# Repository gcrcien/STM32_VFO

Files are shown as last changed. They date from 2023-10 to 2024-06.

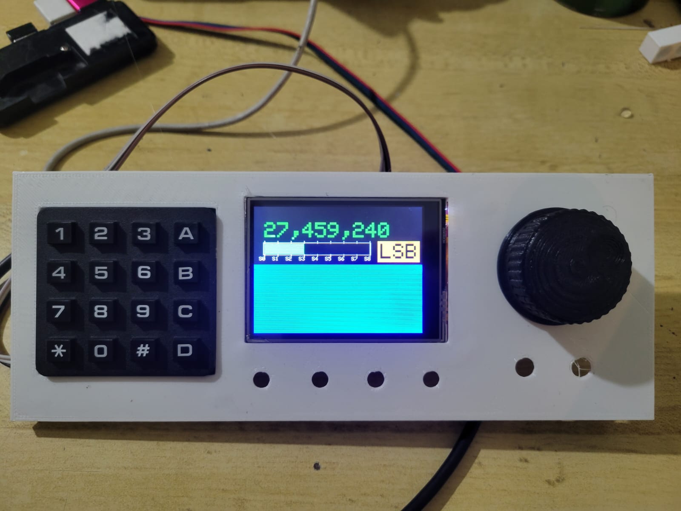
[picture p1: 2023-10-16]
WhatsApp Image 2023-10-15 at 18.07.27.jpeg

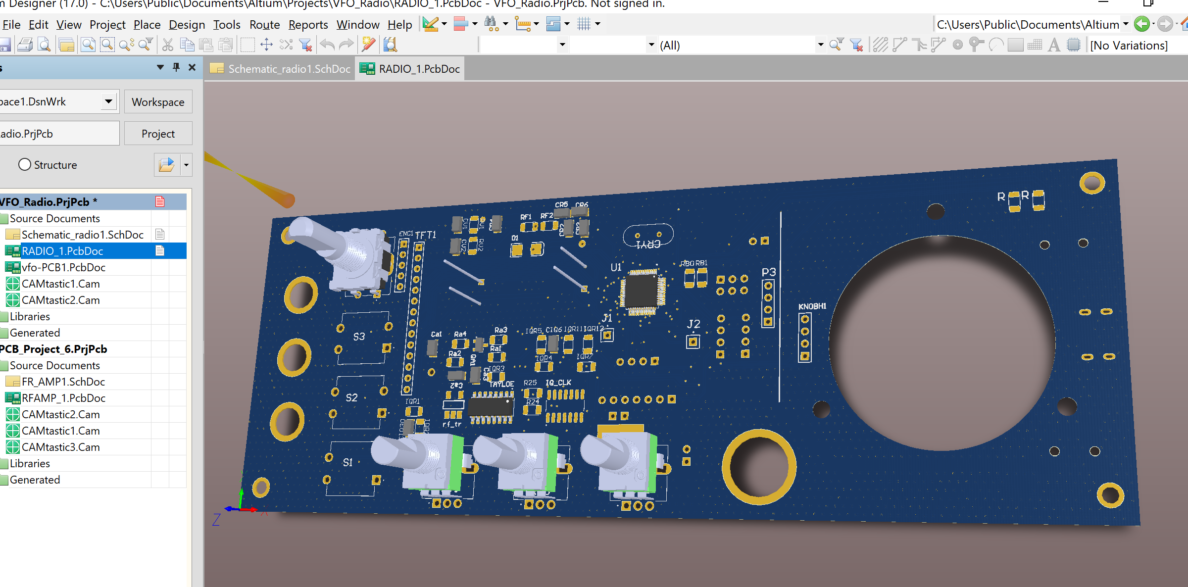
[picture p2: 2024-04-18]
image.png

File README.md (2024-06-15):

# STM32_VFO
VFO for si5351, stm32 and ili9341 2.8" spi tft 

This is the start of a easy to make VFO to use with existing radios or even make your own,
the system interfaces an optical encoder on pins B12 and B13, a big SPI display a clasic tft 2.8 ILI9341,
a matrix 4x4 Keypad using I2C interface with PCF8574, i know the screen has touch inputs
however i like to have a tactile input and the keypad just feels better.

Te MCU is constantly monitoring a few things, for example the audio level on receive.
Some radios use the same meter for audio receive and modulation measurement which this radio would be suited for.

WhatsApp Image 2023-10-15 at 18 07 27 (1)

The system is currently coded with spanish languaje but this would be a simple task to translate.
they Keypad input is activated with the "A" key, asks for a frequency in Hz, when this key is pressed again, and if the frequency is 
whithin acceptable range, the value is passed to the VFO and is desplayed.

WhatsApp Image 2023-11-06 at 07 51 49

Recently i was able to include a simple spectrum view, its just a FFT of the input of my radio, this needs to be downconverted to place the center frequency
of the FFT in the 40khz region, the system shows a 80khz wide view around your frequency of interest, in my case i just tapped my receiver before the IF filter,
this is because the filter is too narrow for more than the desired 2500hz wide area of interest for audio listening.
Its not ideal, the signal is kept into acceptable levels cause i connected the downconverter after the variable gain amp which is controlled by the agc, 
so the signals of interest basically disapear out of the fft view if they are a bit high. Need to fix this, a posible way to do it is basically make a 
mini receiver, so a receiver within a receiver.

Lattest update i have been working on a PCB for the whole project, it handles most fo the VFO part of the system and also includes a Tayloe detector for a realtime sprectrum graph, still needs to be tested, uploaded the Gerber files, PDF and a sch from altium, it also has an IQ output via the 3.5mm jack to connect to sdr++ and act as a SDR via the sound card.


Latest version includes a small waterfall display of the sampled audio 

Watch the video (https://youtu.be/gbz6IhAs6Uw)

More work ahead

18d13fbe-9281-404b-9812-ee0a2d2707f5

This is a work in progress feel free to give me any advice and/or ask any questions

Gustavo :D

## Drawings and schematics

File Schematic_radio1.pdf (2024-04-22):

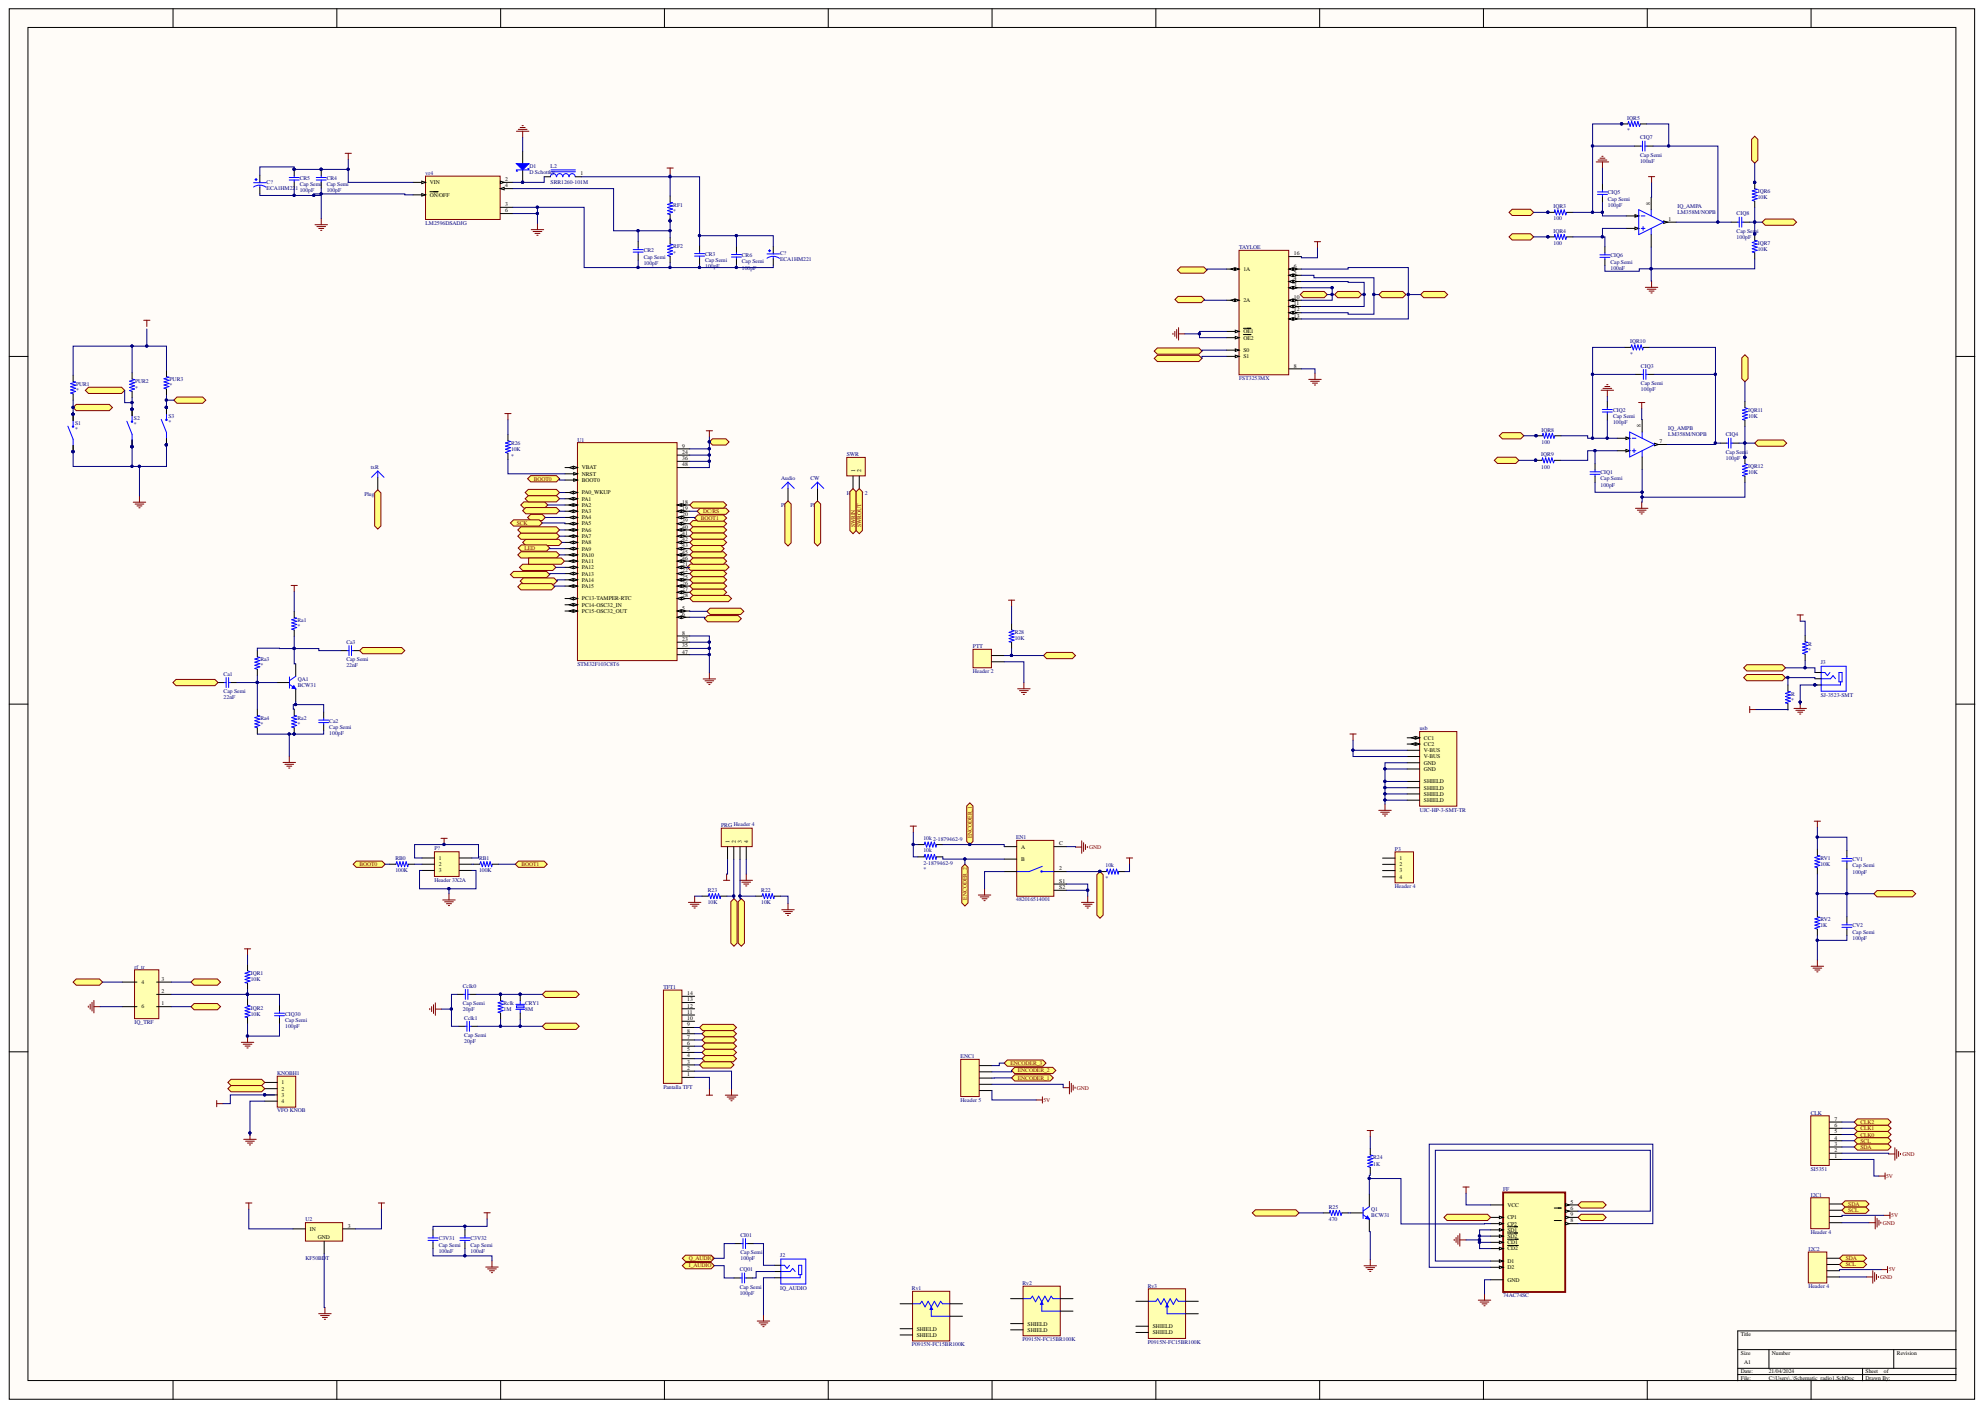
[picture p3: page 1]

UJC-HP-3-SMT-TR

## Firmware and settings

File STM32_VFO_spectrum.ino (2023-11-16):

#include "SPI.h"
#include "Adafruit_ILI9341.h"
#include <Wire.h>
#include <si5351.h>
#include "I2CKeyPad.h"

// Definición de pines para el TFT
#define TFT_CS    PA4
#define TFT_CLK   PA5
#define TFT_MISO  PA6
#define TFT_MOSI  PA7
#define TFT_RST   PB0
#define TFT_DC    PB1
#define AUDIO_IN  PA0

// Constantes para la barra de audio
#define SCALE_X_OFFSET 20
#define AUDIO_BAR_Y_OFFSET 70
#define SCALE_WIDTH 200
#define SCALE_HEIGHT 20
#define NUM_SEGMENTS 9

//Definiciones de la FFT
#define TFT_WIDTH 500
#define TFT_HEIGHT 80
#define GRAPH_TOP_MARGIN 4
#define GRAPH_BOTTOM_MARGIN 4
unsigned int sampling_period_us;
#include "arduinoFFT.h"

arduinoFFT FFT;

#define CHANNEL PA3
const uint16_t samples = 256;
const double samplingFrequency = 100000;
unsigned long microseconds;
int micro1;
unsigned int micro2;
int FFToffset = 29000;
double vReal[samples];
double vImag[samples];

#define SCL_INDEX 0x00
#define SCL_TIME 0x01
#define SCL_FREQUENCY 0x02
#define SCL_PLOT 0x03



// Frecuencia actual
unsigned long currentFrequency = 27185000;

// Inicialización del objeto TFT
Adafruit_ILI9341 tft = Adafruit_ILI9341(TFT_CS, TFT_DC, TFT_RST);

// Dirección del teclado I2C
const uint8_t KEYPAD_ADDRESS = 0x20;
I2CKeyPad keyPad(KEYPAD_ADDRESS);

// Inicialización del Si5351
Si5351 si5351;

// Rangos de frecuencia
unsigned long minFrequency = 26000000;     // Frecuencia mínima de 26 MHz
unsigned long maxFrequency = 28500000;     // Frecuencia máxima de 28.5 MHz
unsigned long frequencyStep = 1000;

// Mapeo de teclas del teclado
char keymap[19] = "D#0*C987B654A321NF";

// Variables para la entrada de frecuencia desde el teclado
String inputNumber = "";
bool inputMode = false;

// Bandera para cambios de frecuencia
bool change = false;

// Offset de frecuencia para mi radio/mezclador
long int IFoffset = 10694700;
int ssbofset = 2500;
int comp = 100;

// Segmento actual en la barra de audio
int segment = 0;

// Cadena de la frecuencia anterior
String oldFrequency_string;

// Intervalo de actualización de audio
unsigned long lastAudioUpdate = 0;
unsigned long audioUpdateInterval = 1;

// Variables para construir la cadena de frecuencia
String shz;
String skhz;
String smhz;
String frequency_string;
//tx state value
bool txState;

// Modo de operación (LSB, AM, USB)
String mode = "LSB";
bool sideband;
bool previousSide;

// Segmento actual en el espectro
int newSegment;

// Valor de entrada de audio
int audioValue;

//PTT
bool ptt = 0;

// Bandera para la exploración de frecuencias
bool scan = false;

void setup() {
  // Inicialización del TFT
  tft.begin();
  tft.setRotation(1);
  tft.fillScreen(ILI9341_BLACK);
  tft.setTextColor(ILI9341_WHITE);
  tft.setTextSize(1);

  //definicion de la frecuencia de muestreo para la fft
  sampling_period_us = round(1000000 * (1.0 / samplingFrequency));


  // Configuración de pines y habilitación de interrupciones para el control de frecuencia
  pinMode(PB12, INPUT_PULLUP);
  pinMode(PB13, INPUT_PULLUP);
  pinMode(PA10, INPUT);
  pinMode(PA9, INPUT);
  attachInterrupt(digitalPinToInterrupt(PB12), clock1_ISR, FALLING);
  attachInterrupt(digitalPinToInterrupt(PB13), clock1_ISR2, FALLING);

  // Inicialización de SPI
  SPI.beginTransaction(SPISettings(20000000, MSBFIRST, SPI_MODE0));

  // Dibujo de la escala en el TFT
  tft.fillRect(0, 110, 320, 240, ILI9341_BLUE);
  drawScale();

  // Actualización del reloj y el modo
  clock_update();
  get_mode();

  // Inicialización de la comunicación I2C y carga del mapeo del teclado
  Wire.begin();
  Wire.setClock(400000);
  keyPad.loadKeyMap(keymap);

  //FFT y sus marcos
  tft.fillRect(1, 151, 250, 76, ILI9341_BLACK);
  tft.drawRect(0, 150, 252, 77, ILI9341_WHITE);
  for (int x = 25; x <= 252; x += 25) {
    tft.drawFastVLine(x, 225, 8, ILI9341_WHITE);
  }

  // Agregar los números desde -25 kHz hasta +25 kHz
  for (int i = 0; i <= 50; i += 5) {
    int i2;
    tft.setTextColor(ILI9341_WHITE);
    tft.setTextSize(0);
    tft.setCursor(2 + (i ) * 5, 230); // Ajusta las coordenadas según tus necesidades
    if (i < 25) {
      i2 = (( i - 25) *  - 1);
    }
    else {
      i2 = i - 25;
    }
    tft.print(i2);
  }



  // Inicialización del Si5351
  si5351.init(SI5351_CRYSTAL_LOAD_8PF, 0, 0);
  si5351.drive_strength(SI5351_CLK0, SI5351_DRIVE_8MA);
  si5351.output_enable(SI5351_CLK0, 1);
  si5351.drive_strength(SI5351_CLK2, SI5351_DRIVE_2MA);
  si5351.output_enable(SI5351_CLK2, 1);
  si5351.set_freq((27175000) * SI5351_FREQ_MULT, SI5351_CLK2);

  //BORRAR DESPUES
  ptt = digitalRead(PA10);
  tft.fillRoundRect(235, 110, 80, 40, 2, ILI9341_GREEN);
  tft.setCursor(250, 115);
  tft.setTextSize(4);
  tft.setTextColor(ILI9341_BLACK);
  tft.print("RX");
  ptt = digitalRead(PA10);
  sideband = digitalRead(PA9);
  if (!sideband) {
    mode = "USB";
    IFoffset = 10697200 - ssbofset;  // Procesamiento del teclado
  }

  if (sideband) {
    mode = "LSB";
    IFoffset = 10697200 + ssbofset;       // Procesamiento del teclado
  }
  get_mode();
  if (ptt) {
    tft.setCursor(250, 115);
    tft.setTextSize(4);
    tft.setTextColor(ILI9341_BLACK);
    tft.print("TX");
  }

}

// Manejador de interrupción para el control de frecuencia (giro de perilla)
void clock1_ISR() {
  bool dir = digitalRead(PB13);
  if (dir == true) {
    currentFrequency += 10;
  }
  if (dir == false) {
    currentFrequency -= 10;
  }
  change = true;
}

// Manejador de interrupción para el control de frecuencia (giro de perilla)
void clock1_ISR2() {
  bool dir = digitalRead(PB12);
  if (dir == true) {
    currentFrequency -= 10;
  }
  if (dir == false) {
    currentFrequency += 10;
  }
  change = true;
}

// Dibuja la escala en el TFT
void drawScale() {
  tft.drawRect(SCALE_X_OFFSET - 2, AUDIO_BAR_Y_OFFSET - 2, SCALE_WIDTH + 4, SCALE_HEIGHT + 4, ILI9341_WHITE);
  int segmentWidth = SCALE_WIDTH / NUM_SEGMENTS;
  int scaleValue = 0;
  tft.drawRect(SCALE_X_OFFSET, AUDIO_BAR_Y_OFFSET, SCALE_WIDTH, SCALE_HEIGHT, ILI9341_WHITE);
  for (int i = 0; i <= NUM_SEGMENTS; i++) {
    int x = SCALE_X_OFFSET + i * segmentWidth;
    tft.drawFastVLine(x, AUDIO_BAR_Y_OFFSET - 5, SCALE_HEIGHT + 10, ILI9341_WHITE);
    tft.setCursor(x - 10, AUDIO_BAR_Y_OFFSET + SCALE_HEIGHT + 5);
    tft.setTextSize(1);
    tft.setTextColor(ILI9341_WHITE);
    tft.print("S" + String(scaleValue));
    scaleValue += 9 / NUM_SEGMENTS;
  }
}

// Actualiza la visualización del número de entrada en el TFT
void updateInputNumberDisplay() {
  tft.setCursor(30, 10);
  tft.setTextSize(2);
  tft.setTextColor(ILI9341_GREEN);
  tft.print(inputNumber);
}

// Actualiza la información de frecuencia en el TFT
void clock_update() {
  f_string();
  tft.setCursor(20, 30);
  tft.setTextSize(4);
  tft.setTextColor(ILI9341_BLACK);
  tft.print(oldFrequency_string);
  tft.setCursor(20, 30);
  tft.setTextSize(4);
  tft.setTextColor(ILI9341_GREEN);
  tft.print(frequency_string);
  oldFrequency_string = frequency_string;
  change = false;
}

// Lee el valor de entrada de audio
void audio_peek() {
  audioValue = analogRead(AUDIO_IN);

  // Calcula el nuevo segmento
  newSegment = audioValue / (600 / NUM_SEGMENTS);

  // Limita el nuevo segmento para que no sea mayor que NUM_SEGMENTS - 1
  if (newSegment >= NUM_SEGMENTS) {
    newSegment = NUM_SEGMENTS - 1;
  }

  if (newSegment != segment) {
    tft.fillRoundRect(SCALE_X_OFFSET, AUDIO_BAR_Y_OFFSET, SCALE_WIDTH, SCALE_HEIGHT, 2, ILI9341_BLACK);

    int segmentWidth = SCALE_WIDTH / NUM_SEGMENTS;
    segment = newSegment;

    for (int i = 0; i <= segment; i++) {
      int x = SCALE_X_OFFSET + i * segmentWidth;
      if (i >= NUM_SEGMENTS - 1) {
        tft.fillRoundRect(x, AUDIO_BAR_Y_OFFSET, segmentWidth, SCALE_HEIGHT, 2, ILI9341_RED);
      } else if (i == 6 || i == 7) {
        tft.fillRoundRect(x, AUDIO_BAR_Y_OFFSET, segmentWidth, SCALE_HEIGHT, 2, ILI9341_YELLOW);
      } else {
        tft.fillRoundRect(x, AUDIO_BAR_Y_OFFSET, segmentWidth, SCALE_HEIGHT, 2, ILI9341_GREEN);
      }
    }
  }
}

// Construye la cadena de frecuencia en formato MHz, kHz y Hz
void f_string() {
  int mhz = currentFrequency / 1000000;
  int khz = (currentFrequency % 1000000) / 1000;
  int hz = currentFrequency - ((mhz * 1000000) + (khz * 1000));

  smhz = String(mhz);
  if (mhz < 10 && mhz >= 1) {
    smhz = " " + String(mhz);
  }

  if (hz >= 100) {
    shz = "," + String(hz);
  }
  if (hz < 100 && hz > 10) {
    shz = ",0" + String(hz);
  }
  if (hz < 10 && hz >= 1) {
    shz = ",00" + String(hz);
  }
  if (hz == 0) {
    shz = ",000";
  }

  if (khz >= 100) {
    skhz = "," + String(khz);
  }
  if (khz < 100 && khz > 10) {
    skhz = ",0" + String(khz);
  }
  if (khz < 10 and khz >= 1) {
    skhz = ",00" + String(khz);
  }
  if (khz == 0) {
    skhz = ",000";
  }

  frequency_string = smhz + skhz + shz;
}

// Procesa la entrada del teclado
void keypadInput() {
  int oldClock = currentFrequency;
  char ch = keyPad.getChar();
  int key = keyPad.getLastKey();
  if (ch == '*') {
    scan = !scan;
  }

  if (ch == 'A') {
    if (!inputMode) {
      inputMode = true;
      inputNumber = "";
    } else {
      int number = inputNumber.toInt();
      inputMode = false;

      change = true;
      if (number > 21000 && number < 50000) {
        currentFrequency = (number * 1000);
      }
      else if (number < 21000 || number > 50000) {
        currentFrequency = oldClock;
      }
    }
  } else if (inputMode) {
    if (isdigit(ch)) {
      inputNumber += ch;
    }
  }
  if (inputMode) {
    tft.fillRect(270, 25, 60, 30, ILI9341_GREEN);
    tft.setCursor(150, 12);
    tft.setTextSize(1.5);
    tft.setTextColor(ILI9341_GREEN);
    tft.print("Introduzca frecuencia");
  }
  if (!inputMode) {
    tft.fillRect(270, 25, 60, 30, ILI9341_BLACK);
  }
}

// Muestra el modo de operación en el TFT
void get_mode() {
  tft.fillRoundRect(235, 65, 80, 40, 2, ILI9341_ORANGE);
  tft.setCursor(240, 72);
  tft.setTextSize(4);
  tft.setTextColor(ILI9341_BLACK);
  tft.print(mode);
}


void loop() {

  if (ptt && !txState) {
    txState = true;
    tft.fillRoundRect(235, 110, 80, 40, 2, ILI9341_RED);
    tft.setCursor(250, 115);
    tft.setTextSize(4);
    tft.setTextColor(ILI9341_BLACK);
    tft.print("TX");
    //si5351.set_freq((currentFrequency - IFoffset + 2500) * SI5351_FREQ_MULT, SI5351_CLK0);
  }

  if (!ptt && txState) {
    txState = false;
    tft.fillRoundRect(235, 110, 80, 40, 2, ILI9341_GREEN);
    tft.setCursor(250, 115);
    tft.setTextSize(4);
    tft.setTextColor(ILI9341_BLACK);
    tft.print("RX");
  }
  // Exploración de frecuencias
  if (scan) {
    if (change) {
      scan = !scan;
    }
    if (currentFrequency <= maxFrequency) {
      currentFrequency += frequencyStep;
      si5351.set_freq((currentFrequency - IFoffset + comp) * SI5351_FREQ_MULT, SI5351_CLK0);
      si5351.set_freq((currentFrequency - FFToffset + comp) * SI5351_FREQ_MULT, SI5351_CLK2);
      clock_update();
      audio_peek();
      delay(20);
      if (audioValue > 90) {
        scan = !scan;
      }
    }
    if (currentFrequency > maxFrequency) {
      scan = !scan;
    }
  }

  // Actualización de audio y frecuencia
  unsigned long currentMillis = millis();
  if (currentMillis - lastAudioUpdate >= audioUpdateInterval) {
    ptt = digitalRead(PA10);
    sideband = digitalRead(PA9);

    // Llamada a la función performFFT para realizar la FFT y obtener los datos
    //performFFT();
    // Llamada a la función drawFFTGraph para dibujar la gráfica de la FFT
    //drawFFTGraph(vReal, samples, tft, 0, 150);
    performFFTAndDrawGraph(1, 150);

    if (!sideband) {
      mode = "USB";
      IFoffset = 10697200 - ssbofset;  // Procesamiento del teclado
    }

    if (sideband) {
      mode = "LSB";
      IFoffset = 10697200 + ssbofset;       // Procesamiento del teclado
    }
    if (previousSide != sideband) {
      si5351.set_freq((currentFrequency - IFoffset + comp) * SI5351_FREQ_MULT, SI5351_CLK0);
      si5351.set_freq((currentFrequency - FFToffset + comp) * SI5351_FREQ_MULT, SI5351_CLK2);
      previousSide = sideband;
      get_mode();

    }
    audio_peek();
    lastAudioUpdate = currentMillis;
    if (change) {
      clock_update();
      si5351.set_freq((currentFrequency - IFoffset + comp) * SI5351_FREQ_MULT, SI5351_CLK0);
      si5351.set_freq((currentFrequency - FFToffset + comp) * SI5351_FREQ_MULT, SI5351_CLK2);

    }
  }

  // Procesamiento del teclado
  if (keyPad.isPressed()) {
    keypadInput();
    updateInputNumberDisplay();
    delay(200);
    if (!inputMode) {
      tft.fillRect(20, 5, 270, 25, ILI9341_BLACK);
      inputNumber = "";
    }
  }

}

void performFFTAndDrawGraph(int xOffset, int yOffset) {

  microseconds = micros();
  for (int i = 0; i < samples; i++) {
    vReal[i] = analogRead(CHANNEL);
    vImag[i] = 0;
    while (micros() - microseconds < sampling_period_us) {
    }
    microseconds += sampling_period_us;
  }

  FFT = arduinoFFT(vReal, vImag, samples, samplingFrequency);
  FFT.Windowing(FFT_WIN_TYP_RECTANGLE, FFT_FORWARD);
  FFT.Compute(FFT_FORWARD);
  FFT.ComplexToMagnitude();

  // Eliminar las 3 primeras magnitudes
  vReal[0] = 0;
  vReal[1] = 0;
  unsigned int fft_time = micros() - micro2;

  // Configura los márgenes y dimensiones del gráfico
  int graphWidth = TFT_WIDTH;
  int graphHeight = TFT_HEIGHT - GRAPH_TOP_MARGIN - GRAPH_BOTTOM_MARGIN;
  int startX = xOffset;
  int startY = GRAPH_TOP_MARGIN + graphHeight + yOffset;

  // Calcula el ancho de cada barra en el gráfico
  float barWidth = static_cast<float>(graphWidth) / samples;

  // Encuentra el valor máximo en los datos de la FFT
  int maxMagnitude = 0.0;
  for (int i = 0; i < samples / 2; i++) {
    if (vReal[i] > maxMagnitude) {
      maxMagnitude = vReal[i];
    }
  }
  if (maxMagnitude < 5000) {
    maxMagnitude = 5000;
  }
  tft.fillRoundRect(39, 140, 50, 10, 2, ILI9341_GREEN);
  tft.setCursor(40, 141);
  tft.setTextSize(1);
  tft.setTextColor(ILI9341_BLACK);
  tft.print(maxMagnitude);
  // Dibuja las barras de la gráfica con 1 píxel de ancho
  for (int i = 0; i < samples / 2; i++) {
    // Calcula la altura de la barra según el valor de la FFT
    int barHeight = static_cast<int>((vReal[i] / maxMagnitude) * graphHeight);

    // Calcula la posición de inicio de la barra
    int x = startX + static_cast<int>(i * barWidth);
    int y1 = startY - barHeight;

    // Dibuja la barra como una línea vertical de 1 píxel de ancho
    tft.drawFastVLine(x, 152, 73, ILI9341_BLACK);
    tft.drawFastVLine(x, y1, barHeight, ILI9341_GREEN);
  }


}

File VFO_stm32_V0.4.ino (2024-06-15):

#include "SPI.h"
#include "Adafruit_ILI9341.h"
#include <Wire.h>
#include <si5351.h>

// Definición de pines para el TFT
#define TFT_CS    PA4
#define TFT_CLK   PA5
#define TFT_MISO  PA6
#define TFT_MOSI  PA7
#define TFT_RST   PB0
#define TFT_DC    PB1
#define AUDIO_IN  PA0
#define TR_PIN    PA1
#define BAT  PA3
#define BLUE            0x008B

// Constantes para la barra de audio
#define SCALE_X_OFFSET 20
#define AUDIO_BAR_Y_OFFSET 70
#define SCALE_WIDTH 200
#define SCALE_HEIGHT 10
#define NUM_SEGMENTS 9

//Definiciones de la FFT
#define TFT_WIDTH 256
#define TFT_HEIGHT 40
#define GRAPH_TOP_MARGIN 4
#define GRAPH_BOTTOM_MARGIN 4
int sampling_period_us;
#include "arduinoFFT.h"

arduinoFFT FFT;

#define CHANNEL PA0
const uint16_t samples = 256;
int samplingFrequency = 10000;
unsigned long microseconds;
int micro1;
unsigned int micro2;
int FFToffset = 29000;
double vReal[samples];
double vImag[samples];
int maxMagnitude = 0.0;
#define NUM_WATERFALL_ROWS 20
int waterfallData[NUM_WATERFALL_ROWS][128] = {0};

// Frecuencia actual
unsigned int currentFrequency = 7000000;

// Inicialización del objeto TFT
Adafruit_ILI9341 tft = Adafruit_ILI9341(TFT_CS, TFT_DC, TFT_RST);

// Inicialización del Si5351
Si5351 si5351;

// Rangos de frecuencia
int TR_offset;

// Bandera para cambios de frecuencia
bool change = false;

// Offset de frecuencia para mi radio/mezclador
long int IFoffset = 39994000;

// Segmento actual en la barra de audio
int segment = 0;

// Cadena de la frecuencia anterior
String oldFrequency_string;

// Intervalo de actualización de audio
unsigned long lastAudioUpdate = 0;
unsigned long audioUpdateInterval = 80;

// Variables para construir la cadena de frecuencia
String shz;
String skhz;
String smhz;
String frequency_string;

// Modo de operación (LSB, AM, USB)
String mode = "LSB";
int modeNumber = 0;
// Definición del menu
bool boton = 0;
int amount = 10;
int knob = 1000;
int oldknob = 0;
bool boton1 = 0;
int clockF = 0;
int menu = 0;
bool steps = 0;
int paso = 100;
bool powerString = "SI5351_DRIVE_8MA";
int power = 1;
bool bandC = 0;
bool powerC;
float vBat;
float oldvBat;
int interval = 150;
int debounceT = 15;
int offset2lo;
bool W;
// Definición de la barra de espectro
#define SPECTRUM_X_OFFSET 20
#define SPECTRUM_Y_OFFSET 150
#define SPECTRUM_WIDTH 280
#define SPECTRUM_HEIGHT 60
#define SPECTRUM_MIN_FREQ 26000000UL
#define SPECTRUM_MAX_FREQ 28500000UL


// Arreglo para almacenar los niveles de señal del espectro
int spectrumData[SPECTRUM_WIDTH];

// Valor de entrada de audio
int audioValue;


void setup() {
  //Aceleracion del adc
  adc_set_prescaler(ADC_PRE_PCLK2_DIV_2) ;
  //adc_set_sample_rate(ADC2, ADC_SMPR_7_5);
  adc_set_sample_rate(ADC2, ADC_SMPR_1_5);



  // Inicialización del TFT
  tft.begin();
  tft.setRotation(3);
  tft.fillScreen(ILI9341_BLACK);
  tft.setTextColor(ILI9341_WHITE);
  tft.setTextSize(1);
  sampling_period_us = round(1000000 * (1.0 / samplingFrequency));

  // Configuración de pines y habilitación de interrupciones para el control de frecuencia
  pinMode(PB11, INPUT_PULLUP);
  pinMode(PB12, INPUT_PULLUP);
  pinMode(PB15, INPUT_PULLUP);
  pinMode(PA8, INPUT_PULLUP);
  pinMode(PB3, INPUT_PULLUP);
  pinMode(PB4, INPUT_PULLUP);
  pinMode(PB8, INPUT_PULLUP);
  pinMode(PB5, INPUT_PULLUP);
  pinMode(PA9, OUTPUT);
  digitalWrite(PA9, HIGH);
  pinMode(TR_PIN, INPUT_PULLDOWN);
  attachInterrupt(digitalPinToInterrupt(PB11), knob_ISR1, FALLING);
  attachInterrupt(digitalPinToInterrupt(PB15), knob_ISR2, FALLING);
  attachInterrupt(digitalPinToInterrupt(PA8), clock1_ISR3, FALLING);
  attachInterrupt(digitalPinToInterrupt(PB3), clock1_ISR4, FALLING);
  attachInterrupt(digitalPinToInterrupt(PB4), boton1_ISR5, FALLING);
  attachInterrupt(digitalPinToInterrupt(PB8), boton2_ISR6, FALLING);
  attachInterrupt(digitalPinToInterrupt(PB5), boton3_ISR7, FALLING);



  tft.drawRect(SCALE_X_OFFSET - 2, AUDIO_BAR_Y_OFFSET - 2, SCALE_WIDTH + 4, SCALE_HEIGHT + 4, ILI9341_WHITE);
  int segmentWidth = SCALE_WIDTH / NUM_SEGMENTS;
  tft.drawRect(SCALE_X_OFFSET, AUDIO_BAR_Y_OFFSET, SCALE_WIDTH, SCALE_HEIGHT, ILI9341_WHITE);
  for (int i = 0; i <= NUM_SEGMENTS; i++) {
    int x = SCALE_X_OFFSET + i * segmentWidth;
    tft.drawFastVLine(x, AUDIO_BAR_Y_OFFSET - 5, SCALE_HEIGHT + 10, ILI9341_WHITE);
    int currentScaleValue =  i;
    // Dibujar el nuevo segmento y el número
    tft.drawFastVLine(x, AUDIO_BAR_Y_OFFSET - 5, SCALE_HEIGHT + 10, ILI9341_WHITE);
    tft.setCursor(x - 10, AUDIO_BAR_Y_OFFSET + SCALE_HEIGHT + 5);
    tft.setTextSize(1);
    tft.setTextColor(ILI9341_WHITE);
    tft.print("S" + String(currentScaleValue));
  }




  // Inicialización de SPI
  SPI.beginTransaction(SPISettings(1000000, MSBFIRST, SPI_MODE0));

  // Dibujo de la escala en el TFT
  tft.fillRect(0, 110, 320, 240, ILI9341_BLACK);
  drawScale();
  //FFT y sus marcos
  //posicion inicial h, posicion v, posicion
  tft.fillRect(1, 110, 256, 70, BLUE);
  tft.drawRect(0, 110, 258, 80, ILI9341_WHITE);
  int p = 0;
  for (int x = 24; x <= 256; x += 30) {
    p++;
    tft.drawFastVLine(x, 185, 8, ILI9341_WHITE);
    tft.setCursor(x + 2, 200);
    tft.setTextColor(ILI9341_WHITE);
    tft.print(String(p) + "k" );
  }

  // Actualización del reloj y el modo
  clock_update();
  get_mode();

  // Inicialización de la comunicación I2C y carga del mapeo del teclado
  Wire.begin();
  Wire.setClock(400000);
  // Inicialización del Si5351
  si5351.init(SI5351_CRYSTAL_LOAD_8PF, 0, 0);
  si5351.drive_strength(SI5351_CLK0, SI5351_DRIVE_2MA);
  si5351.output_enable(SI5351_CLK0, 1);
  si5351.drive_strength(SI5351_CLK1, SI5351_DRIVE_2MA);
  si5351.output_enable(SI5351_CLK1, 1);
  si5351.drive_strength(SI5351_CLK2, SI5351_DRIVE_2MA);
  si5351.output_enable(SI5351_CLK2, 1);
  si5351.set_freq((IFoffset ) * SI5351_FREQ_MULT, SI5351_CLK1);

}

// Manejador de interrupción para el control de frecuencia (giro de perilla)
void knob_ISR1() {
  bool dir = digitalRead(PB12);
  if (dir == true) {
    currentFrequency -= paso;
  }
  if (dir == false) {
    currentFrequency += paso;
  }
  change = true;

  if  (currentFrequency < 500000) {
    currentFrequency = 500000;
  }
  if  (currentFrequency > 30500000) {
    currentFrequency = 30500000;
  }
}

// Manejador de interrupción para el control de frecuencia (giro de perilla)
void knob_ISR2() {
  static unsigned long last_interrupt_time = 0;
  unsigned long interrupt_time = millis();
  if (interrupt_time - last_interrupt_time > debounceT) {
    bool dir = digitalRead(PA8);
    if (dir == true) {
      knob += amount;
    }
    if (dir == false) {
      knob -= amount;
    }
    if  (knob < 0) {
      knob = 0;
    }
    if  (knob > 2500) {
      knob = 2500;
    }
    change = true;
  }
  last_interrupt_time = interrupt_time;

}
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

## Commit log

2023-10-16 Update VFO_stm32_V0.3.ino
    Included keypad input preview, and fixed some graphics
    [VFO_stm32_V0.3.ino]
2023-10-18 Update VFO_stm32_audio.ino
    Weird interaction between keypad and si5351 was crashing upon compilation when si5351 was included
    [VFO_stm32_audio.ino]
2023-10-24 Update VFO_stm32_V0.3.ino
    Aded sideband switch detection and if correction
    [VFO_stm32_V0.3.ino]
2023-11-07 Update STM32_VFO_spectrum.ino
    Fixed some cosmetic stuff, aded numbers to the fft graph
    [STM32_VFO_spectrum.ino]
2023-11-07 Update STM32_VFO_spectrum.ino
    added fft pffsets
2023-11-07 Update STM32_VFO_spectrum.ino
    somehow this works faster, clock 1 takes too much to be setup
    [STM32_VFO_spectrum.ino]
2023-11-16 Update STM32_VFO_spectrum.ino
    way faster fft with just 256 samples
2023-11-21 Update VFO_stm32_V0.3.ino
    ditched the spectrum view as there's no way to deal with the image signals in the fft view, changed some locations and added channel change functions t oyhe B and C keys, included a vfo lock to avoid moving the vfo once a frequency has been selected, channel scan and channel hopping are still enabled in the vfo lock mode
    [VFO_stm32_V0.3.ino]
2024-04-18 Add files via upload
    Included VFO schepatic and PCB files these are untested and not even debugged, uploaded the just as a backup, use them at your own risk
    [Schematic_radio1.SchDoc]
2024-04-22 Delete VFO sch1.pdf
    changed to a newer schematic
2024-04-22 Delete Schematic_radio1.SchDoc
    changed to adifferent schematic
    [Schematic_radio1.SchDoc]
2024-04-22 new files
    made some changes before sending them to jlcpcb
    [Schematic_radio1.SchDoc]
